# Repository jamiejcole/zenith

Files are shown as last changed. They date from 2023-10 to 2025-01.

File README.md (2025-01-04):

# Zenith
An open source EOS controller based on [ETC Lighthack](https://github.com/ETCLabs/lighthack).
I built this to assist with lighting programming alongside an ETC Element 2, more specifically out of my hatred for solely using point-and-click to control my moving heads. Hopefully this project is of use to someone else too.

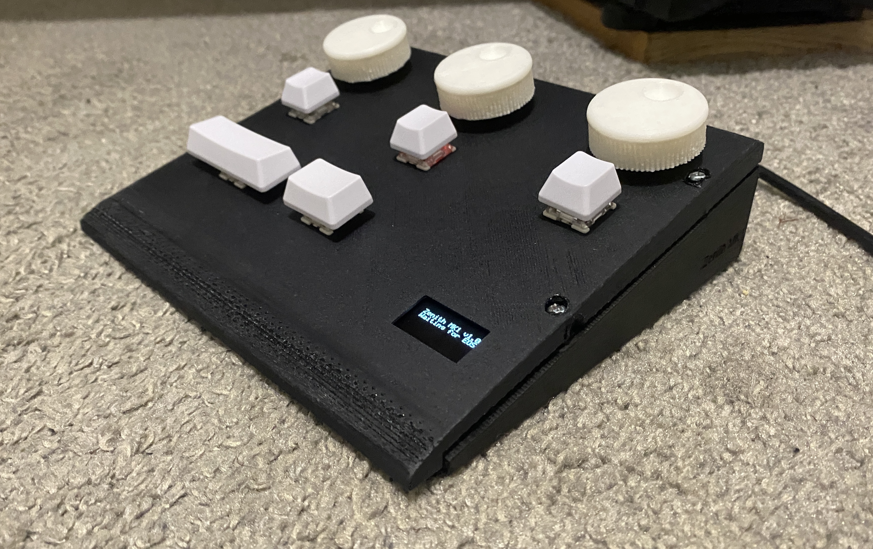
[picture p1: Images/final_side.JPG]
Zenith MK1 Side

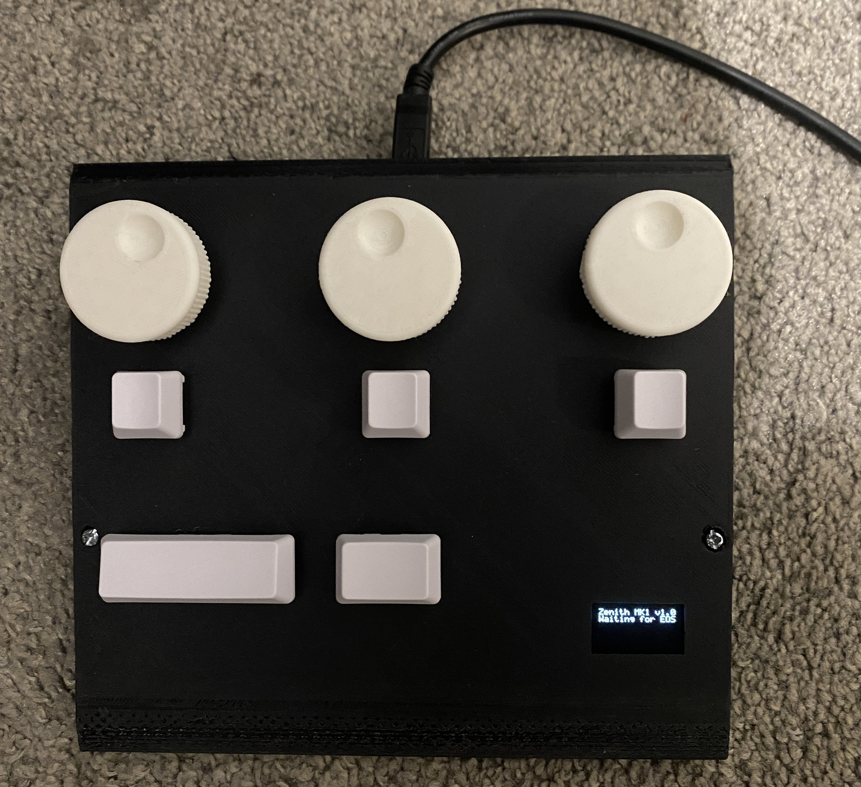
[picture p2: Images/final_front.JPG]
Zenith MK1 Front


## Features
- 3 customisable rotary encoders (default to pan, tilt and zoom)
- 3 cherry MX blue switches to change the action of the corresponding encoder
- Go and stop/back cue buttons
- OLED screen showing current encoder settings and values

## Hardware
To build this, I used:
- 5x cherry MX blue switches
- 3x rotary encoders with pushbuttons
- 0.96 128x64 OLED screen
- Arduino UNO clone
- 3D printed housing and encoder wheels
- 4x M3 threaded inserts

## Notable challenges
Due to using an Arduino clone rather than a genuine one, the arduino had trouble communicating to the Element 2 via OSC over USB, which was a headache to troubleshoot. 
This was mitigated by exiting EOS and using a dodgy workaround to get to control panel and sideloading the Arduino serial drivers by using a USB drive. The comments section of [Nathan Butler's Lighthack](https://tinkering.home.blog/2019/02/19/lighthack-usb-encoder-wing-for-etc-element/) project helped significantly through the process of attempting to get this to work:

>> A couple of things to try:
– The usual driver for the knockoff arduino’s that I’ve used was available at https://learn.sparkfun.com/tutorials/how-to-install-ch340-drivers/all#drivers-if-you-need-them. I downloaded the windows driver from there, put it on a USB, logged into the desk in admin mode, and was able to open the USB drive and just install it.
– Similarly, you could try installing the Arduino software on the ETC desk too, which includes some drivers as part of it’s install.
– Whilst I’m guessing that you’re using the same USB cable at the desk as you did to upload the firmware to the arduino, just in case you are not, try a different USB cable. I have had some funny issues which turned out to be an intermittently faulty cable
Hope that helps!

>> Element 2 CH340 Driver install
> Any update on this? I have a win7 element 2 console and my arduino uno clone is not being recognised at all in diagnostics page. It's using the CH340 chipset, really struggling to get this to work. Is there any way i can install the drivers onto the console?

Update on this, was able to install the correct drivers by:
- loading into the console ECU,
- spamming shift to open the sticky keys menu
- clicking the hyperlink on the prompt to open control panel
- open device manager from control panel
- find the COM port for the Arduino 
- insert usb with extracted .zip folder for windows 7 CH340 drivers, downloaded from [this page](https://www.wch-ic.com/downloads/CH341SER_ZIP.html)
- click update drivers 
- select update from local file
- find extracted driver folder on USB
- install drivers
- exit out of all windows and launch EOS primary
- COM4 port is now recognised and can talk to Arduino via OSC over USB

## Wiring
Here was my 'circuit diagram' for the build.
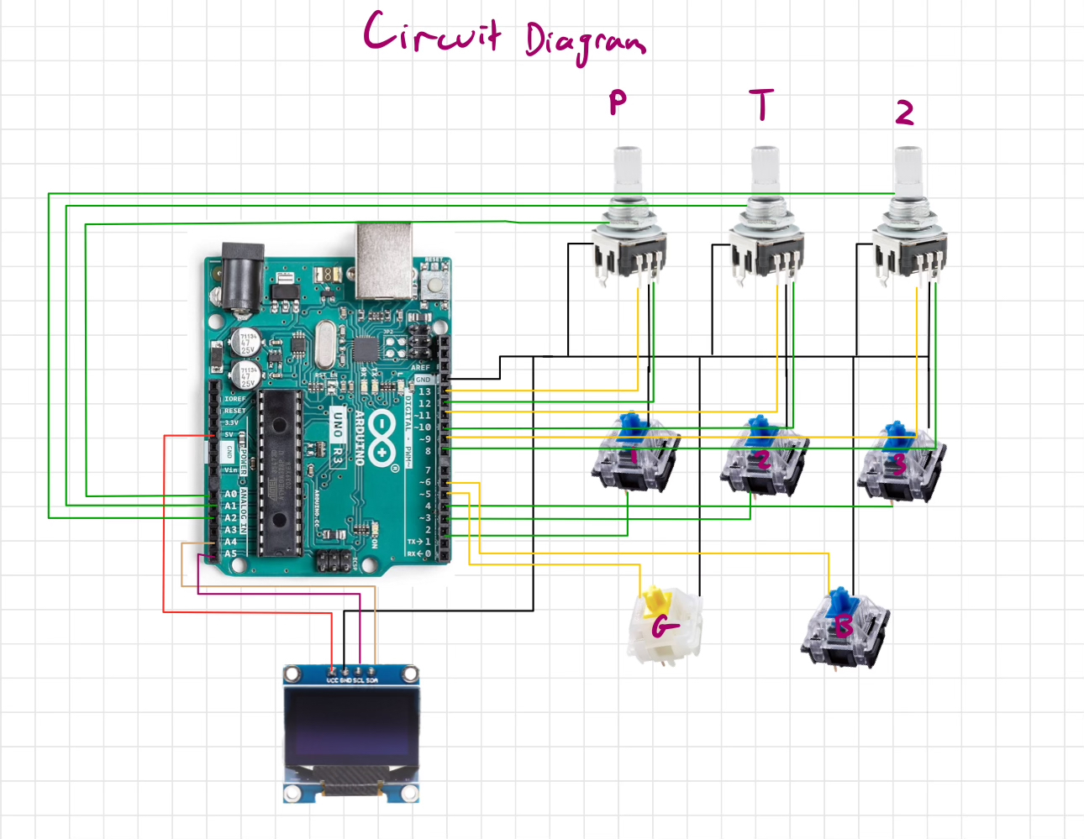
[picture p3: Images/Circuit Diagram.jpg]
Circuit Diagram


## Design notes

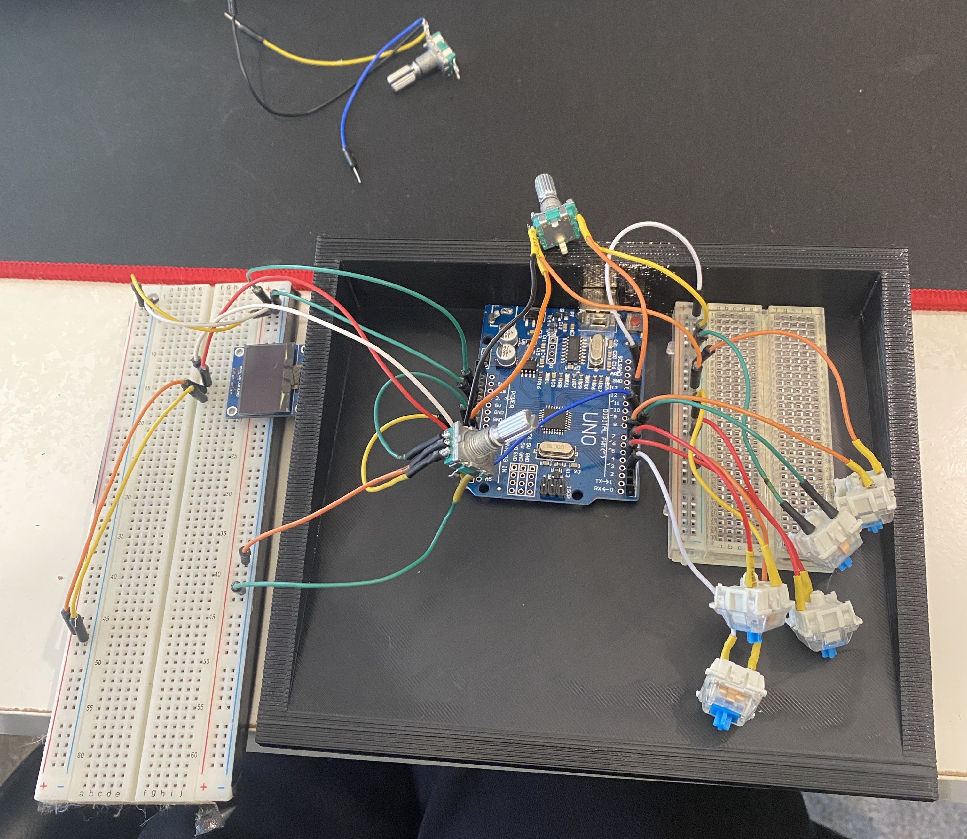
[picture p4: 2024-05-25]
Images/prototyping.JPG

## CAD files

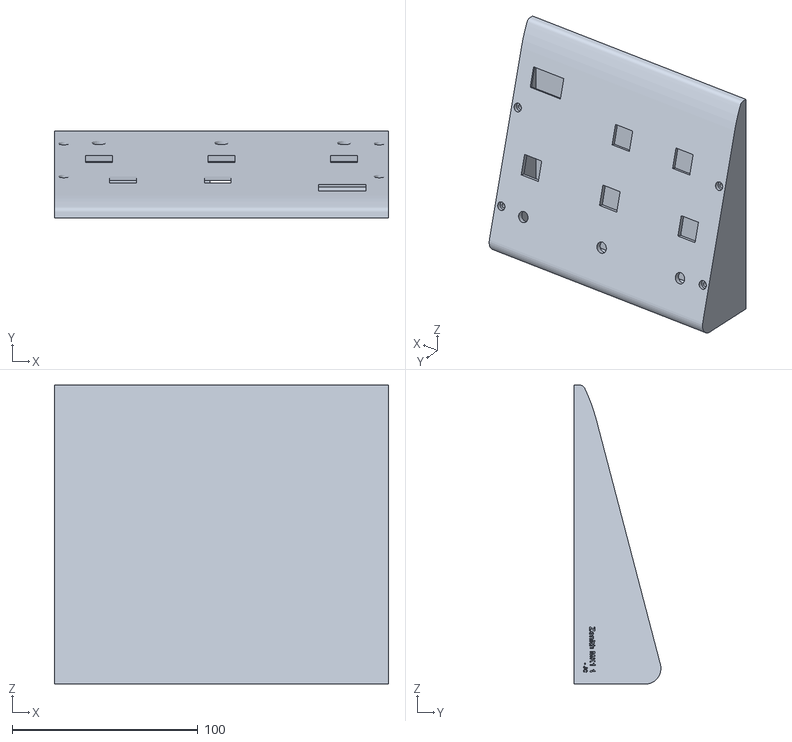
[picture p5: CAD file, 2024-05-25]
3D Files/ZenithMK1.stl
180.0 x 46.8 x 161.0

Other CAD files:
3D Files/ZenithMK1.f3d

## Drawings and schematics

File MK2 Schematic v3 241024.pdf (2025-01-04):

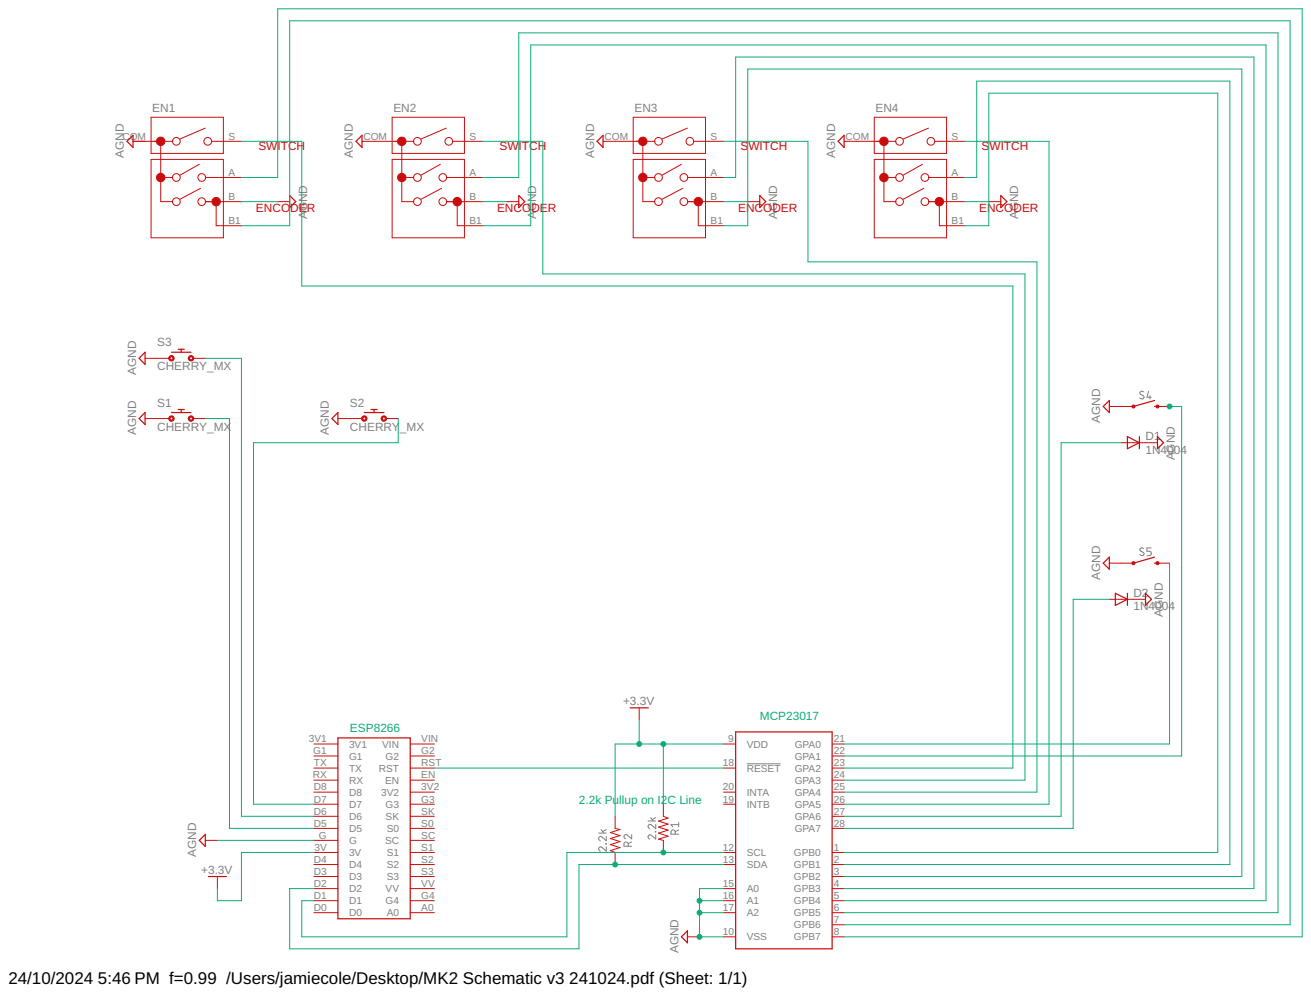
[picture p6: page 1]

24/10/2024 5:46 PM f=0.99 /Users/jamiecole/Desktop/MK2 Schematic v3 241024.pdf (Sheet: 1/1)

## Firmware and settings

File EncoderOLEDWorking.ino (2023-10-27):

#include <OSCBoards.h>
#include <OSCBundle.h>
#include <OSCData.h>
#include <OSCMatch.h>
#include <OSCMessage.h>
#include <OSCTiming.h>

#include <Wire.h>
#include "SSD1306Ascii.h"
#include "SSD1306AsciiWire.h"

#ifdef BOARD_HAS_USB_SERIAL
#include <SLIPEncodedUSBSerial.h>
SLIPEncodedUSBSerial SLIPSerial(thisBoardsSerialUSB);
#else
#include <SLIPEncodedSerial.h>
SLIPEncodedSerial SLIPSerial(Serial);
#endif
#include <string.h>

// consts
#define I2C_ADDRESS 0x3C
#define RST_PIN -1
SSD1306AsciiWire oled;


//buttons
#define enc1ModeButton 2
#define enc2ModeButton 3
#define enc3ModeButton 4
#define goButton 5
#define backButton 6
#define enc1PushButton A0
#define enc2PushButton A1
#define enc3PushButton A2

#define SUBSCRIBE           ((int32_t)1)
#define UNSUBSCRIBE         ((int32_t)0)

#define EDGE_DOWN           ((int32_t)1)
#define EDGE_UP             ((int32_t)0)

#define FORWARD             0
#define REVERSE             1

// Change these values to switch which direction increase/decrease pan/tilt
#define PAN_DIR             FORWARD
#define TILT_DIR            FORWARD
#define ZOOM_DIR            FORWARD

#define PAN_SCALE           2
#define TILT_SCALE          2
#define ZOOM_SCALE          2
 
#define SIG_DIGITS          3   // Number of significant digits displayed

#define OSC_BUF_MAX_SIZE    512

const String HANDSHAKE_QUERY = "ETCOSC?";
const String HANDSHAKE_REPLY = "OK";

#define VERSION_STRING      "1.0"

#define BOX_NAME_STRING     "Zenith MK1"

#define PING_AFTER_IDLE_INTERVAL    2500
#define TIMEOUT_AFTER_IDLE_INTERVAL 5000


// Local types
enum WHEEL_TYPE { TILT, PAN, ZOOM, EDGE, IRIS, GOBO, GOBO2 };
enum WHEEL_MODE { COARSE, FINE };
WHEEL_MODE currentPanMode = COARSE;
WHEEL_MODE currentTiltMode = COARSE;
WHEEL_MODE currentZoomMode = COARSE;

struct Encoder
{
  uint8_t pinA;
  uint8_t pinB;
  int pinAPrevious;
  int pinBPrevious;
  float pos;
  uint8_t direction;
};
struct Encoder panWheel;
struct Encoder tiltWheel;
struct Encoder zoomWheel;
struct Encoder irisWheel;
struct Encoder edgeWheel;

enum ConsoleType
{
  ConsoleNone,
  ConsoleEos,
};

// Global Vairables

bool updateDisplay = false;
bool screenCleared = true;

ConsoleType connectedToConsole = ConsoleNone;
unsigned long lastMessageRxTime = 0;
bool timeoutPingSent = false;

int prevEnc1ModeButtonState = HIGH;
int prevEnc2ModeButtonState = HIGH;
int prevEnc3ModeButtonState = HIGH;

int currentPanOptionIndex = 0;
int currentTiltOptionIndex = 0;
int currentZoomOptionIndex = 0;
const char* panOptions[] = {"Pan", "Iris", "Gobo 2"};
const char* tiltOptions[] = {"Tilt", "Edge", "Gobo"};
const char* zoomOptions[] = {"Zoom", "Clr Whl"};


float gobo_select = 1.000;

//Local Functions
void issueEosSubscribes()
{
  // Add a filter so we don't get spammed with unwanted OSC messages from Eos
  OSCMessage filter("/eos/filter/add");
  filter.add("/eos/out/param/*");
  filter.add("/eos/out/ping");
  SLIPSerial.beginPacket();
  filter.send(SLIPSerial);
  SLIPSerial.endPacket();

  // Parameters to subscribe to
  const char* params[] = {
    "/pan",
    "/Gobo_Select",
    "/tilt",
    "/zoom",
    "/iris",
    "/edge"
  };

  // Loop through the parameters and subscribe to each
  for (const char* param : params) {
    String address = "/eos/subscribe/param" + String(param);
    OSCMessage subscribeMessage(address.c_str()); // Convert the string to a const char*
    subscribeMessage.add(SUBSCRIBE);
    SLIPSerial.beginPacket();
    subscribeMessage.send(SLIPSerial);
    SLIPSerial.endPacket();
  }
}



void parseFloatGoboSelectUpdate(OSCMessage& msg, int addressOffset)
{
  gobo_select = msg.getOSCData(0)->getFloat();
  updateDisplay = true;
}

void parseFloatPanUpdate(OSCMessage& msg, int addressOffset)
{
  panWheel.pos = msg.getOSCData(0)->getFloat();
  updateDisplay = true;
}

void parseFloatTiltUpdate(OSCMessage& msg, int addressOffset)
{
  tiltWheel.pos = msg.getOSCData(0)->getFloat();
  updateDisplay = true;
}

void parseFloatZoomUpdate(OSCMessage& msg, int addressOffset)
{
  zoomWheel.pos = msg.getOSCData(0)->getFloat();
  updateDisplay = true;
}

void parseFloatEdgeUpdate(OSCMessage& msg, int addressOffset)
{
  edgeWheel.pos = msg.getOSCData(0)->getFloat();
  updateDisplay = true;
}

void parseFloatIrisUpdate(OSCMessage& msg, int addressOffset)
{
  irisWheel.pos = msg.getOSCData(0)->getFloat();
  updateDisplay = true;
}

void parseEos(OSCMessage& msg, int addressOffset)
{
  // If we don't think we're connected, reconnect and subscribe
  if (connectedToConsole != ConsoleEos)
  {
    issueEosSubscribes();
    connectedToConsole = ConsoleEos;
    updateDisplay = true;
  }

  msg.route("/out/param/pan", parseFloatPanUpdate, addressOffset);
  msg.route("/out/param/tilt", parseFloatTiltUpdate, addressOffset);
  msg.route("/out/param/Gobo_Select", parseFloatGoboSelectUpdate, addressOffset);
  msg.route("/out/param/zoom", parseFloatZoomUpdate, addressOffset);
  msg.route("/out/param/iris", parseFloatIrisUpdate, addressOffset);
  msg.route("/out/param/edge", parseFloatEdgeUpdate, addressOffset);
}

/******************************************************************************/


void parseOSCMessage(String& msg)
{
  // check to see if this is the handshake string
  if (msg.indexOf(HANDSHAKE_QUERY) != -1)
  {
    // handshake string found!
    SLIPSerial.beginPacket();
    SLIPSerial.write((const uint8_t*)HANDSHAKE_REPLY.c_str(), (size_t)HANDSHAKE_REPLY.length());
    SLIPSerial.endPacket();

    // An Eos would do nothing until subscribed
    // Let Eos know we want updates on some things
    issueEosSubscribes();

    updateDisplay = true;
  }
  else
  {
    // prepare the message for routing by filling an OSCMessage object with our message string
    OSCMessage oscmsg;
    oscmsg.fill((uint8_t*)msg.c_str(), (int)msg.length());
    // route pan/tilt messages to the relevant update function

    // Try the various OSC routes
    if (oscmsg.route("/eos", parseEos))
      return;
  }
}


// todo - check it works with oled prints
//      - duplicate for other encs
//      - check and scale enc increments by 1x or 0.1x based on state at loop.
// void checkFineCoarseToggles() {
//   static bool defaultState = LOW;
//   bool butt1Pressed = digitalRead(enc1PushButton);
//   if (butt1Pressed != defaultState) {
//     if (butt1Pressed == HIGH) {
//       currentPanMode = (currentPanMode == FINE) ? COARSE : FINE;
//     }
//   }
//   bool butt2Pressed = digitalRead(enc2PushButton);
//   if (butt2Pressed != defaultState) {
//     if (butt2Pressed == HIGH) {
//       currentTiltMode = (currentTiltMode == FINE) ? COARSE : FINE;
//     }
//   }
//   bool butt3Pressed = digitalRead(enc3PushButton);
//   if (butt3Pressed != defaultState) {
//     if (butt3Pressed == HIGH) {
//       currentZoomMode = (currentZoomMode == FINE) ? COARSE : FINE;
//     }
//   }
// }

void checkModeButton(int buttonState, int& prevButtonState, int& currentIndex, const char* options[], int optionCount) {
  if (buttonState == LOW && prevButtonState == HIGH) {
    updateDisplay = true;
    currentIndex = (currentIndex + 1) % optionCount;
    delay(75);
  }
  prevButtonState = buttonState;
}

void checkModeButtons() {
  checkModeButton(digitalRead(enc1ModeButton), prevEnc1ModeButtonState, currentPanOptionIndex, panOptions, sizeof(panOptions) / sizeof(panOptions[0]));
  checkModeButton(digitalRead(enc2ModeButton), prevEnc2ModeButtonState, currentTiltOptionIndex, tiltOptions, sizeof(tiltOptions) / sizeof(tiltOptions[0]));
  checkModeButton(digitalRead(enc3ModeButton), prevEnc3ModeButtonState, currentZoomOptionIndex, zoomOptions, sizeof(zoomOptions) / sizeof(zoomOptions[0]));
}



void displayStatus(const char* mode1, const char* mode2, const char* mode3)
{
  oled.clear();

  switch (connectedToConsole)
  {
    case ConsoleNone:
    {
      oled.println("");
      oled.println("");
      oled.println("    " BOX_NAME_STRING " v" VERSION_STRING);
      oled.println("    Waiting for EOS");
    } break;

    case ConsoleEos:
    {
      Encoder* wheel1 = &panWheel; // Default to pan
      Encoder* wheel2 = &tiltWheel; // Default to tilt
      Encoder* wheel3 = &zoomWheel; // Default to zoom
      int isGobo1 = false;
      int isGobo2 = false;

      if (strcmp(mode1, "Pan") == 0)
        wheel1 = &panWheel;
      else if (strcmp(mode1, "Tilt") == 0)
        wheel1 = &tiltWheel;
      else if (strcmp(mode1, "Zoom") == 0)
        wheel1 = &zoomWheel;
      else if (strcmp(mode1, "Edge") == 0)
        wheel1 = &edgeWheel;
      else if (strcmp(mode1, "Iris") == 0)
        wheel1 = &irisWheel;
      else if (strcmp(mode1, "Gobo") == 0)
        isGobo1 = true;

      if (strcmp(mode2, "Pan") == 0)
        wheel2 = &panWheel;
      else if (strcmp(mode2, "Tilt") == 0)
        wheel2 = &tiltWheel;
      else if (strcmp(mode2, "Zoom") == 0)
        wheel2 = &zoomWheel;
      else if (strcmp(mode2, "Edge") == 0)
        wheel2 = &edgeWheel;
      else if (strcmp(mode2, "Iris") == 0)
        wheel2 = &irisWheel;
      else if (strcmp(mode2, "Gobo") == 0)
        isGobo2 = true;

      if (strcmp(mode3, "Pan") == 0)
        wheel3 = &panWheel;
      else if (strcmp(mode3, "Tilt") == 0)
        wheel3 = &tiltWheel;
      else if (strcmp(mode3, "Zoom") == 0)
        wheel3 = &zoomWheel;
      else if (strcmp(mode3, "Edge") == 0)
        wheel3 = &edgeWheel;
      else if (strcmp(mode3, "Iris") == 0)
        wheel3 = &irisWheel;

      oled.println("");
      oled.println("");
      if (isGobo1)
      {
        oled.println("    1. " + (String)mode1 + ": " + ((isGobo2) ? (int)gobo_select : wheel1->pos));
        oled.println("");
        oled.println("    2. " + (String)mode2 + ": " + ((isGobo1) ? (int)gobo_select : wheel2->pos));
        oled.println("");
        oled.println("    3. " + (String)mode3 + ": " + wheel3->pos);
      }
      else if (isGobo2)
      {
        oled.println("    1. " + (String)mode1 + ": " + wheel1->pos);
        oled.println("");
        oled.println("    2. " + (String)mode2 + ": " + ((isGobo2) ? (int)gobo_select : wheel2->pos));
        oled.println("");
        oled.println("    3. " + (String)mode3 + ": " + wheel3->pos);
      }
      else
      {
        oled.println("    1. " + (String)mode1 + ": " + wheel1->pos);
        oled.println("");
        oled.println("    2. " + (String)mode2 + ": " + wheel2->pos);
        oled.println("");
        oled.println("    3. " + (String)mode3 + ": " + wheel3->pos);
      }
      oled.println("");
    } break;
  }

  updateDisplay = false;
}



void initEncoder(struct Encoder* encoder, uint8_t pinA, uint8_t pinB, uint8_t direction)
{
  encoder->pinA = pinA;
  encoder->pinB = pinB;
  encoder->pos = 0;
  encoder->direction = direction;

  pinMode(pinA, INPUT_PULLUP);
  pinMode(pinB, INPUT_PULLUP);

  encoder->pinAPrevious = digitalRead(pinA);
  encoder->pinBPrevious = digitalRead(pinB);
}

int8_t updateEncoder(struct Encoder* encoder)
{
  int8_t encoderMotion = 0;
  int pinACurrent = digitalRead(encoder->pinA);
  int pinBCurrent = digitalRead(encoder->pinB);

  // has the encoder moved at all?
  if (encoder->pinAPrevious != pinACurrent)
  {
    // Since it has moved, we must determine if the encoder has moved forwards or backwards
    encoderMotion = (encoder->pinAPrevious == encoder->pinBPrevious) ? -1 : 1;

    // Adjust motion based on the current mode
    encoderMotion *= 1.5; // Coarse mode adjustment

    // If we are in reverse mode, flip the direction of the encoder motion
    if (encoder->direction == REVERSE)
      encoderMotion = -encoderMotion;
  }
  encoder->pinAPrevious = pinACurrent;
  encoder->pinBPrevious = pinBCurrent;

  return encoderMotion;
}



void sendOscMessage(const String &address, float value)
{
  OSCMessage msg(address.c_str());
  msg.add(value);
  SLIPSerial.beginPacket();
  msg.send(SLIPSerial);
  SLIPSerial.endPacket();
}

void sendEosGoboSelect(float value) {
  value = value/4;
  gobo_select += value;
  if (gobo_select <= 0.5)
    gobo_select = 1;
  // todo: clamp gobo_select to retrieved max value (ensure it's a float!)

  String oscAddress = "/eos/param/Gobo_Select";
  OSCMessage msg(oscAddress.c_str());
  msg.add(gobo_select);
  msg.add(0.500 + gobo_select);
  msg.add(1.500 + gobo_select);
  SLIPSerial.beginPacket();
  msg.send(SLIPSerial);
  SLIPSerial.endPacket();
}

void sendEosWheelMove(WHEEL_TYPE type, float ticks)
{
  String wheelMsg("/eos/wheel");
  wheelMsg.concat("/coarse");

  if (type == PAN)
    wheelMsg.concat("/pan");
  else if (type == TILT)
    wheelMsg.concat("/tilt");
  else if (type == ZOOM)
    wheelMsg.concat("/zoom");
  else if (type == IRIS)
    wheelMsg.concat("/iris");
  else if (type == EDGE)
    wheelMsg.concat("/edge");
  else
    // something has gone very wrong
    return;

  sendOscMessage(wheelMsg, ticks);
}


/******************************************************************************/

void sendWheelMove(const char* name, float ticks) {
  WHEEL_TYPE type;
  if (strcmp(name, "Tilt") == 0)
    type = TILT;
  else if (strcmp(name, "Pan") == 0)
    type = PAN;
  else if (strcmp(name, "Zoom") == 0)
    type = ZOOM;
  else if (strcmp(name, "Iris") == 0)
    type = IRIS;
  else if (strcmp(name, "Edge") == 0)
    type = EDGE;
  else if (strcmp(name, "Gobo") == 0)
    type = GOBO; // Added Gobo type  
  
  switch (connectedToConsole) {
    default:
    case ConsoleEos:
      if (type == GOBO) {
        // Handle Gobo selection differently
        sendEosGoboSelect(ticks);
      } else {
        // Handle other parameters like Pan, Tilt, etc.
        sendEosWheelMove(type, ticks);
      }
      break;
  }
}



void sendKeyPress(bool down, const String &key)
{
  String keyAddress;
  switch (connectedToConsole)
  {
    default:
    case ConsoleEos:
      keyAddress = "/eos/key/" + key;
      break;
  }
  OSCMessage keyMsg(keyAddress.c_str());

  if (down)
    keyMsg.add(EDGE_DOWN);
  else
    keyMsg.add(EDGE_UP);

  SLIPSerial.beginPacket();
  keyMsg.send(SLIPSerial);
  SLIPSerial.endPacket();
}

void checkButtons() {
  const int keyCount = 2;
  const int keyPins[2] = {goButton, backButton};
  const String keyNames[2] = {"NEXT", "LAST"};

  static int keyStates[2] = {HIGH, HIGH};

  for (int keyNum = 0; keyNum < keyCount; ++keyNum) {
    int currentState = digitalRead(keyPins[keyNum]);
    if (currentState != keyStates[keyNum]) {
      sendKeyPress(currentState == HIGH, keyNames[keyNum]);
      keyStates[keyNum] = currentState;
    }
  }
}

void setup()
{
  pinMode(enc1ModeButton, INPUT_PULLUP);
  pinMode(enc2ModeButton, INPUT_PULLUP);
  pinMode(enc3ModeButton, INPUT_PULLUP);
  pinMode(enc1PushButton, INPUT_PULLUP);
  pinMode(enc2PushButton, INPUT_PULLUP);
  pinMode(enc3PushButton, INPUT_PULLUP);

  pinMode(goButton, INPUT_PULLUP);
  pinMode(backButton, INPUT_PULLUP);

  Wire.begin();
  Wire.setClock(400000L);

  #if RST_PIN >= 0
    oled.begin(&Adafruit128x64, I2C_ADDRESS, RST_PIN);
  #else // RST_PIN >= 0
    oled.begin(&Adafruit128x64, I2C_ADDRESS);
  #endif // RST_PIN >= 0

  oled.setFont(System5x7);
  oled.clear();
  oled.println("");
  oled.println("");
  oled.println("    Starting Up...");
  delay(1000);

  SLIPSerial.begin(115200);
  // This is a hack around an Arduino bug. It was taken from the OSC library
  //examples
#ifdef BOARD_HAS_USB_SERIAL
  while (!SerialUSB);
#else
  while (!Serial);
#endif

  // This is necessary for reconnecting a device because it needs some time
  // for the serial port to open. The handshake message may have been sent
  // from the console before #lighthack was ready

  SLIPSerial.beginPacket();
  SLIPSerial.write((const uint8_t*)HANDSHAKE_REPLY.c_str(), (size_t)HANDSHAKE_REPLY.length());
  SLIPSerial.endPacket();

  // If it's an Eos, request updates on some things
  issueEosSubscribes();

  initEncoder(&panWheel, 12, 13, PAN_DIR);
  initEncoder(&tiltWheel, 11, 10, TILT_DIR);
  initEncoder(&zoomWheel, 9, 8, ZOOM_DIR);

  displayStatus(panOptions[currentPanOptionIndex], tiltOptions[currentTiltOptionIndex], zoomOptions[currentZoomOptionIndex]);
}


void loop()
{
  // checkFineCoarseToggles();
  checkModeButtons();
  static String curMsg;
  int size;
  // get the updated state of each encoder
  int32_t panMotion = updateEncoder(&panWheel);
  int32_t tiltMotion = updateEncoder(&tiltWheel);
  int32_t zoomMotion = updateEncoder(&zoomWheel);

  // check for next/last updates
  checkButtons();

  // now update our wheels
  // float tiltScaleFactor = (currentTiltMode == FINE) ? 0.1 : 1.0;
  // float panScaleFactor = (currentPanMode == FINE) ? 0.1 : 1.0;
  // float zoomScaleFactor = (currentZoomMode == FINE) ? 0.1 : 1.0;

  if (tiltMotion != 0)
    sendWheelMove(tiltOptions[currentTiltOptionIndex], tiltMotion);

  if (panMotion != 0)
    sendWheelMove(panOptions[currentPanOptionIndex], panMotion);

  if (zoomMotion != 0)
    sendWheelMove(zoomOptions[currentZoomOptionIndex], zoomMotion);

  // Then we check to see if any OSC commands have come from Eos
  // and update the display accordingly.
  size = SLIPSerial.available();
  if (size > 0)
  {
    // Fill the msg with all of the available bytes
    while (size--)
      curMsg += (char)(SLIPSerial.read());
  }
  if (SLIPSerial.endofPacket())
  {
    parseOSCMessage(curMsg);
    lastMessageRxTime = millis();
    // We only care about the ping if we haven't heard recently
    // Clear flag when we get any traffic
    timeoutPingSent = false;
    curMsg = String();
  }

  if (lastMessageRxTime > 0)
  {
    unsigned long diff = millis() - lastMessageRxTime;
    //We first check if it's been too long and we need to time out
    if (diff > TIMEOUT_AFTER_IDLE_INTERVAL)
    {
      connectedToConsole = ConsoleNone;
      lastMessageRxTime = 0;
      updateDisplay = true;
      timeoutPingSent = false;
    }

    //It could be the console is sitting idle. Send a ping once to
    // double check that it's still there, but only once after 2.5s have passed
    if (!timeoutPingSent && diff > PING_AFTER_IDLE_INTERVAL)
    {
      OSCMessage ping("/eos/ping");
      ping.add(BOX_NAME_STRING "_hello"); // This way we know who is sending the ping
      SLIPSerial.beginPacket();
      ping.send(SLIPSerial);
      SLIPSerial.endPacket();
      timeoutPingSent = true;
    }
  }

  if (updateDisplay) {
    if (screenCleared) {
      // Clear the screen only if it's not already cleared
      oled.clear();
      screenCleared = true;
    }
    displayStatus(panOptions[currentPanOptionIndex], tiltOptions[currentTiltOptionIndex], zoomOptions[currentZoomOptionIndex]);  // Display the updated status
    screenCleared = false;
    updateDisplay = false;
  }
}

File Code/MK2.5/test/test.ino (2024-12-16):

#include <Arduino.h>
#include <Wire.h>
#include <string.h>
#include <OSCBoards.h>
#include <OSCBundle.h>
#include <OSCData.h>
#include <OSCMatch.h>
#include <OSCMessage.h>
#include <OSCTiming.h>
#include "Bounce2mcp.h"
#include "Adafruit_MCP23017.h"
#include "Rotary.h"
#include "RotaryEncOverMCP.h"

#ifdef BOARD_HAS_USB_SERIAL
#include <SLIPEncodedUSBSerial.h>
SLIPEncodedUSBSerial SLIPSerial(thisBoardsSerialUSB);
#else
#include <SLIPEncodedSerial.h>
SLIPEncodedSerial SLIPSerial(Serial);
#endif

#define NUM_BUTTONS 4
#define MCP_PIN_MX1_SHIFT 4
#define MCP_PIN_MX2_GO 5
#define MCP_PIN_MX3_STOP 6
#define MCP_PIN_MX4_PAGE 7
#define OSC_BUF_MAX_SIZE 512
#define PING_AFTER_IDLE_INTERVAL 2500
#define TIMEOUT_AFTER_IDLE_INTERVAL 5000

const int LED_R = 14;
const int LED_G = 12;
const int LED_B = 13;

const uint8_t BUTTON_PINS[NUM_BUTTONS] = {
  MCP_PIN_MX1_SHIFT,
  MCP_PIN_MX2_GO,
  MCP_PIN_MX3_STOP,
  MCP_PIN_MX4_PAGE
};

const char* encoderFunctions[][4] = {
  {"pan", "tilt", "zoom", "edge"}, // page 1
  {"red", "green", "blue", "iris"} // page 2
};

int currentPage = 0;
const int TICK_AMOUNT = 2;
int shiftState = 0;

enum ConsoleType
{
  ConsoleNone,
  ConsoleEos,
};
const String HANDSHAKE_QUERY = "ETCOSC?";
const String HANDSHAKE_REPLY = "OK";

ConsoleType connectedToConsole = ConsoleNone;
unsigned long lastMessageRxTime = 0;
bool timeoutPingSent = false;

BounceMcp * buttons = new BounceMcp[NUM_BUTTONS];
Adafruit_MCP23017 mcp;

/* function prototypes */
void RotaryEncoderChanged(bool clockwise, int id);
void sendOscMessage(const String &address, float value);
void startupBlink();
void waitingForConnectionBlink();
void readyBlink();
void parseOscMessage(String &msg);
void issueEosSubscribes();
void activatePage(int page);
void sendKeyPress(const String &key, int shiftMod = -1);
void writeLED(int r, int g, int b);

RotaryEncOverMCP rotaryEncoders[] = {
    RotaryEncOverMCP(&mcp, 8, 9, &RotaryEncoderChanged, 1),
    RotaryEncOverMCP(&mcp, 10, 11, &RotaryEncoderChanged, 2),
    RotaryEncOverMCP(&mcp, 12, 13, &RotaryEncoderChanged, 3),
    RotaryEncOverMCP(&mcp, 14, 15, &RotaryEncoderChanged, 4),
};
constexpr int numEncoders = (int)(sizeof(rotaryEncoders) / sizeof(*rotaryEncoders));

void RotaryEncoderChanged(bool clockwise, int id) {
  Serial.println(
    "Encoder " + String(id) + ": "
    + (clockwise ? String("clockwise") : String("counter-clock-wise"))
  );
  sendEncoderMovement(currentPage, id - 1, (clockwise ? -TICK_AMOUNT : TICK_AMOUNT));
}

void writeLED(int r, int g, int b) {
  analogWrite(LED_R, r);
  analogWrite(LED_G, g);
  analogWrite(LED_B, b);
}

void readyBlink() {
  analogWrite(LED_R,   0);
  analogWrite(LED_G, 255);
  analogWrite(LED_B,  0);
  delay(350);
  analogWrite(LED_G, 0);
  delay(100);
  analogWrite(LED_G, 255);
  delay(350);
  analogWrite(LED_G, 0);
}

void startupBlink() {
  writeLED(255, 0, 0);
  delay(500);
  writeLED(0, 0, 0);
  delay(100);
  writeLED(0, 255, 0);
  delay(500);
  writeLED(0, 0, 0);
  delay(100);
  writeLED(0, 0, 255);
  delay(500);
  writeLED(0, 0, 0);
  delay(100);
}

void waitingForConnectionBlink() {
  analogWrite(LED_R,   255);
  analogWrite(LED_G, 0);
  analogWrite(LED_B,  0);
  delay(400);
  analogWrite(LED_R, 0);
  delay(200);
  analogWrite(LED_R, 255);
  delay(400);
  analogWrite(LED_R, 255);
}

void pollAll() {
  uint16_t gpioAB = mcp.readGPIOAB();
  for (int i = 0; i < numEncoders; i++) {
    rotaryEncoders[i].feedInput(gpioAB);
  }
}

void sendOscMessage(const String &address, float value) {
  OSCMessage msg(address.c_str());
  msg.add(value);
  SLIPSerial.beginPacket();
  msg.send(SLIPSerial);
  SLIPSerial.endPacket();
}

void sendEncoderMovement(int page, int encoder, float ticks) {
  // we want to send a string e.g. /eos/wheel/coarse/pan
  float sentTicks = ticks;
  // if (page == 0 && encoder == 3) { 
  //   sentTicks *= 2; // double ticks for intensity
  //   String wheelMsg("/eos/wheel/1/level");
  //   sendOscMessage(wheelMsg, sentTicks);
  // }
  // else {
    String wheelMsg("/eos/wheel");
    wheelMsg.concat("/coarse/");
    wheelMsg.concat(encoderFunctions[page][encoder]);
    sendOscMessage(wheelMsg, sentTicks);
  // }
}

void issueEosSubscribes() {
  // Adding a filter to only listen for pings
  OSCMessage filter("/eos/filter/add");
  // filter.add("/eos/out/param/*");
  filter.add("/eos/out/ping");

  SLIPSerial.beginPacket();
  filter.send(SLIPSerial);
  SLIPSerial.endPacket();
}

void parseOscMessage(String &msg) {
  // If it's a handshake string, reply
  if (msg.indexOf(HANDSHAKE_QUERY) != -1) {
    SLIPSerial.beginPacket();
    SLIPSerial.write((const uint8_t*)HANDSHAKE_REPLY.c_str(), (size_t)HANDSHAKE_REPLY.length());
    SLIPSerial.endPacket();

    // Subscribe to ping message
    issueEosSubscribes();
  }
}

void activatePage(int page) {
  if (page == 0) {
    writeLED(186, 61, 34);
    currentPage = 0;
  }
  else if (page == 1) {
    writeLED(34, 186, 148);
    currentPage = 1;
  }
  else {
    return;
  }
}

void sendKeyPress(const String &key, int shiftMod) {
  String msg = "/eos/key/" + key;
  if (shiftMod == 1) {
    sendOscMessage(msg, 1.0);
    shiftState = 1;
  }
  else if (shiftMod == 0) {
    sendOscMessage(msg, 0.0);
    shiftState = 0;
  }
  else {
    OSCMessage keyMsg(msg.c_str());
    SLIPSerial.beginPacket();
    keyMsg.send(SLIPSerial);
    SLIPSerial.endPacket();
  }
}

void setup(){
  delay(2000); // Give time for bootup to finish

  Wire.begin();
  Wire.setClock(400000);

  mcp.begin();

  // Initialize LED
  pinMode(LED_R, OUTPUT);
  pinMode(LED_G, OUTPUT);
  pinMode(LED_B, OUTPUT);

  //Initialize input encoders (pin mode, interrupt)
  for(int i=0; i < numEncoders; i++) {
      rotaryEncoders[i].init();
  }

  // Initialize buttons
  for (int i = 0; i < NUM_BUTTONS; i++) {
    mcp.pinMode(BUTTON_PINS[i], INPUT);
    mcp.pullUp(BUTTON_PINS[i], HIGH);
    buttons[i].attach(mcp, BUTTON_PINS[i], 2);
  }

  // Ready! 
  startupBlink();

  // OSC Library hack to avoid Arduino bug
  SLIPSerial.begin(115200);
  #ifdef BOARD_HAS_USB_SERIAL
    while (!SerialUSB);
  #else
    while (!Serial);
  #endif

  // Needed for device reconnection
  SLIPSerial.beginPacket();
  SLIPSerial.write((const uint8_t*)HANDSHAKE_REPLY.c_str(), (size_t)HANDSHAKE_REPLY.length());
  SLIPSerial.endPacket();

  issueEosSubscribes();

  delay(500);
  readyBlink();

  delay(100);
  activatePage(0);
}
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

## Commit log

2024-05-25 added model and pics
    [ZenithMK1.f3d, ZenithMK1.stl]
2024-11-01 got all wheels working
2024-12-16 added pcb files
    [ElementWing.kicad_pcb, ElementWing.kicad_sch, bom.csv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]
2024-12-16 added drawings
    [ElementWingFacePlatev2.dxf]
2024-12-16 ordered pcb
    [ElementWing.kicad_pcb, ElementWing.kicad_sch, bom.csv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]
2025-01-04 moved element wing to separate repo
    [ElementWing.kicad_pcb, ElementWing.kicad_sch, ElementWing.step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]
